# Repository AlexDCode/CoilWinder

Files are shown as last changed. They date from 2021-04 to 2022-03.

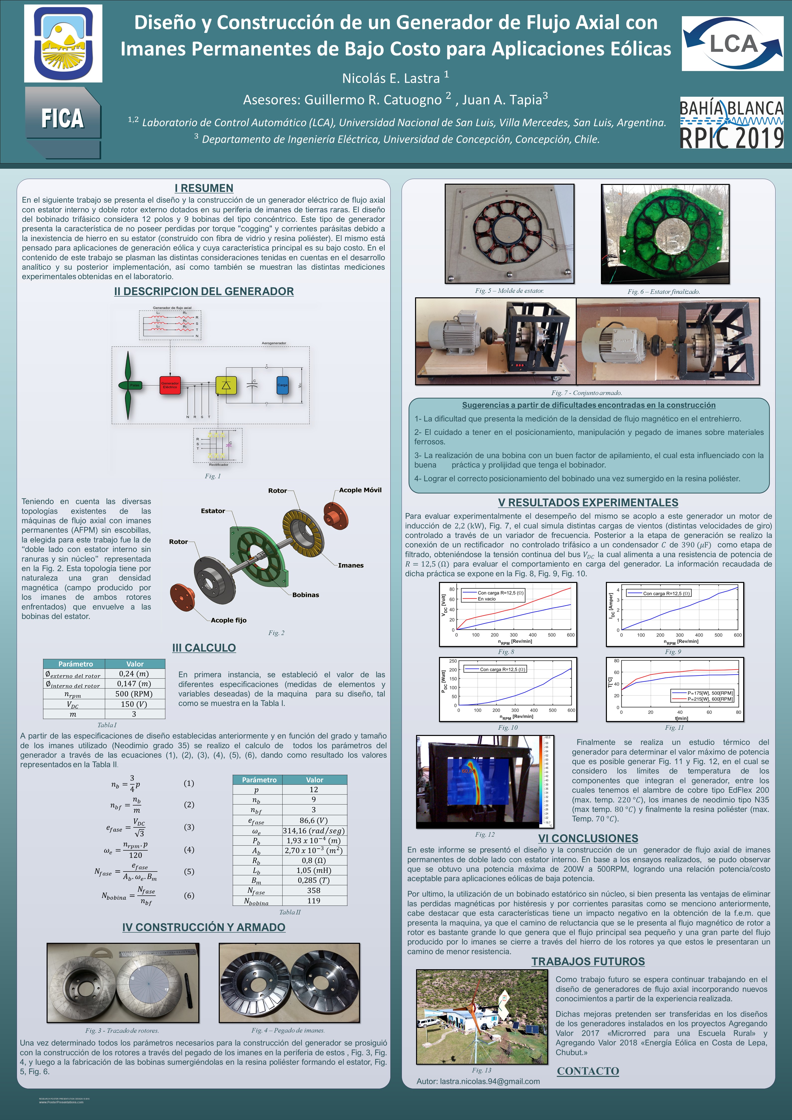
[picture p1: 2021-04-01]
docs/literature/PosterRPICestudiantilLastraNicolas-FormatoJPEG.jpg

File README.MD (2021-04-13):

# Coil Winder Final Project



## Introduction
The goal of the project is to develop an automatic coil winding machine using commands via the serial communication.

This is just a place to store and share source code, images, and important references for documentation.

Place the source code inside the src folder, the libraries for the code in the lib folder, media files in the assets folder, and other documentation at the docs folder.

## TODO:
    * MasterControl:
      * Creating the LCD display Menu
        * Configure and Run CoilWinder
        * Progress Screen
        * Settings
      * Create a send command function that takes the parameters for the instruction and sends the data in Serial/I2C Bus
      * Use I2C for sending and receiving commands and connect to SparkFun Quiic Interface Bus
    * CoilWinder:
      * Create a send command function that takes the parameters for the instruction and sends the data in Serial/I2C Bus (also in MasterControl)
      * Use I2C for sending and receiving commands and connect to SparkFun Quiic Interface Bus (also in MasterControl)
      * Add Pinout description from hardware/Schematics/Circuit Pinouts.docx in the intro commentary @ghiraldo5
      * Verify Command Instruction Set to be compressed to 1 byte instruction, that would only make the instruction command and number to be send in a single packet and represented by an hex number @ByteCommando
      * Verify parsing function to identify and execute commands (Consider separating instruction command and number as needed) @ByteCommando
      * Create overrideSpeed() function to change the speed of the winding to a percentage of the established RPM using a potentiometer @AlexDCode
      * Create overideFeederOffset() to change the feeder offset during execution @AlexDCode
    * Hardware
      * Upgrade to Trinamic TMC2208 stepper drivers

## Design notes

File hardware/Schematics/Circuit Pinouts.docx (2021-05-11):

# Microcontroller

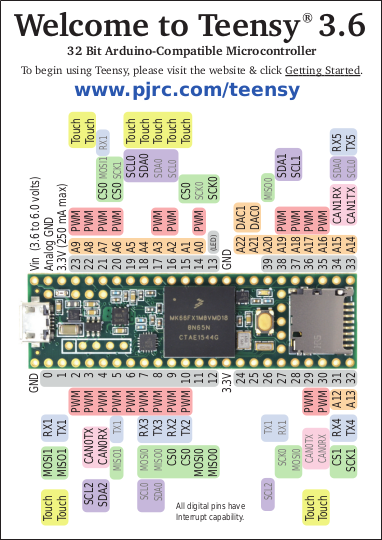
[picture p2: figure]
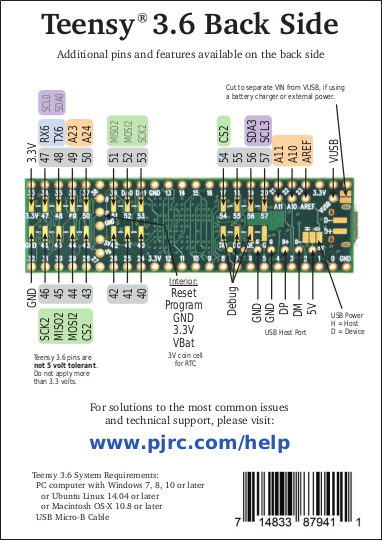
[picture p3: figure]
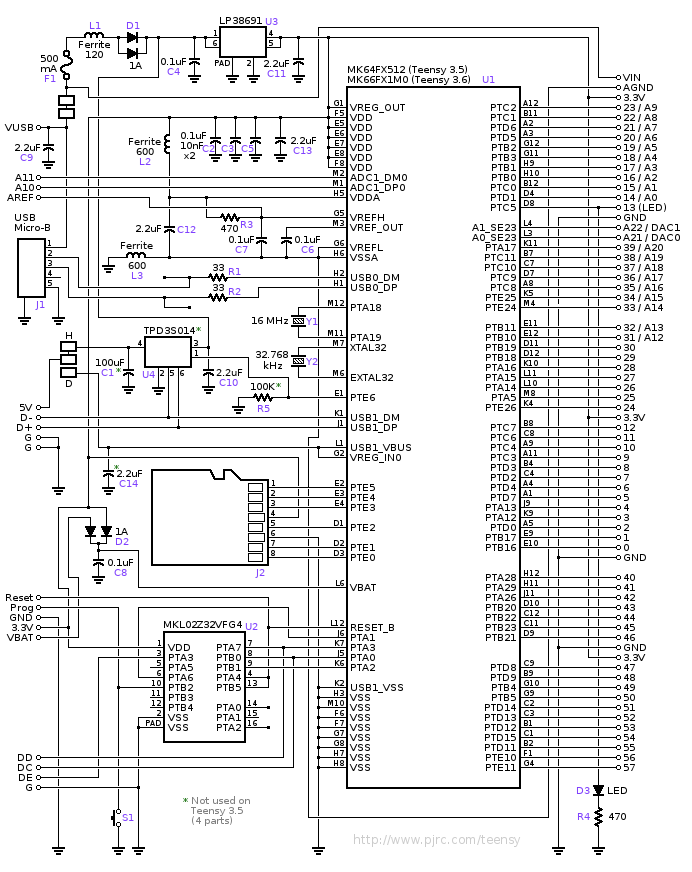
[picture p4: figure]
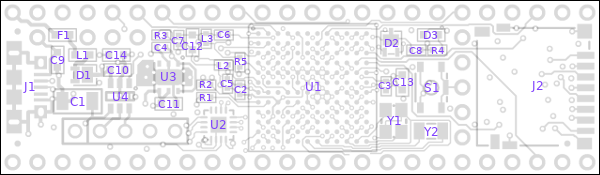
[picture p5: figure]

https://www.pjrc.com/teensy/schematic.html

# A4988 Stepper Motor Driver

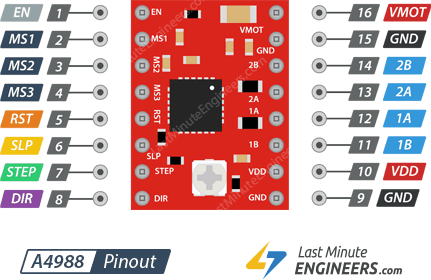
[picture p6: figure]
A4988 Stepper Motor Driver Pinout

https://lastminuteengineers.com/a4988-stepper-motor-driver-arduino-tutorial/

# Pinout Table

Teensy 3.6 | Description | Terminal Connection
0 | RX1 Communication with slave | Slave TX
1 | TX1 Communication with slave | Slave RX
7 | End stop micro switch: Feeder Secondary Tower | -
8 | End stop micro switch: Feeder Primary Tower | -
21 | Feeder Enable | Feeder A4988: EN
20 | Feeder MS1 | Feeder A4988: MS1
19 | Feeder MS2 | Feeder A4988: MS2
18 | Feeder MS3 | Feeder A4988: MS3
17 | Feeder Reset | Feeder A4988: RST
16 | Feeder Sleep | Feeder A4988: SLP
15 | Feeder Step | Feeder A4988: STEP
14 | Feeder Direction | Feeder A4988: DIR
31 | Spindle Enable | Spindle A4988: EN
32 | Spindle MS1 | Spindle A4988: MS1
39 | Spindle MS2 | Spindle A4988: MS2
38 | Spindle MS3 | Spindle A4988: MS3
35 | Spindle Reset | Spindle A4988: RST
34 | Spindle Sleep | Spindle A4988: SLP
37 | Spindle Step | Spindle A4988: STEP
36 | Spindle Direction | Spindle A4988: DIR
| SDA
| SCL

# Variables

#define Constants for Pins

Name | Description | Value
PIN_RX | RX1 Communication with slave | 0
PIN_TX | TX1 Communication with slave | 1
PIN_END_STOP_2 | End stop micro switch: Feeder Secondary Tower | 7
PIN_END_STOP_1 | End stop micro switch: Feeder Primary Tower | 8
PIN_FEEDER_EN | Feeder Enable | 21
PIN_FEEDER_MS1 | Feeder MS1 | 20
PIN_FEEDER_MS2 | Feeder MS2 | 19
PIN_FEEDER_MS3 | Feeder MS3 | 18
PIN_FEEDER_RST | Feeder Reset | 17
PIN_FEEDER_SLP | Feeder Sleep | 16
PIN_FEEDER_STEP | Feeder Step | 15
PIN_FEEDER_DIR | Feeder Direction | 14
PIN_SPINDLE_EN | Spindle Enable | 31
PIN_SPINDLE_MS1 | Spindle MS1 | 32
PIN_SPINDLE_MS2 | Spindle MS2 | 39
PIN_SPINDLE_MS3 | Spindle MS3 | 38
PIN_SPINDLE_RST | Spindle Reset | 35
PIN_SPINDLE_SLP | Spindle Sleep | 34
PIN_SPINDLE_STEP | Spindle Step | 37
PIN_SPINDLE_DIR | Spindle Direction | 36
SERIAL_BAUD_RATE | Serial Baud Rate | 115200

# Useful Links

- https://learn.sparkfun.com/tutorials/getting-started-with-the-teensy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
- https://lastminuteengineers.com/a4988-stepper-motor-driver-arduino-tutorial/
- https://www.pjrc.com/store/teensy36.html

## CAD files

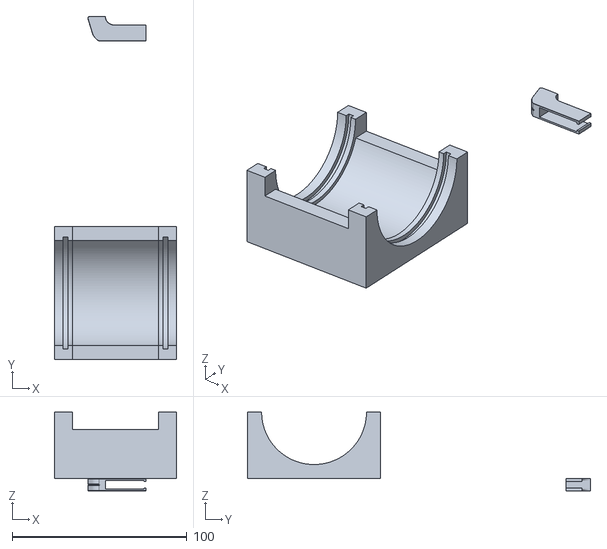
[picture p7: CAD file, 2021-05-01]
hardware/The Machine/3D Models/Coil Winder - Feeder Guide Base.stl
70.0 x 196.3 x 45.1

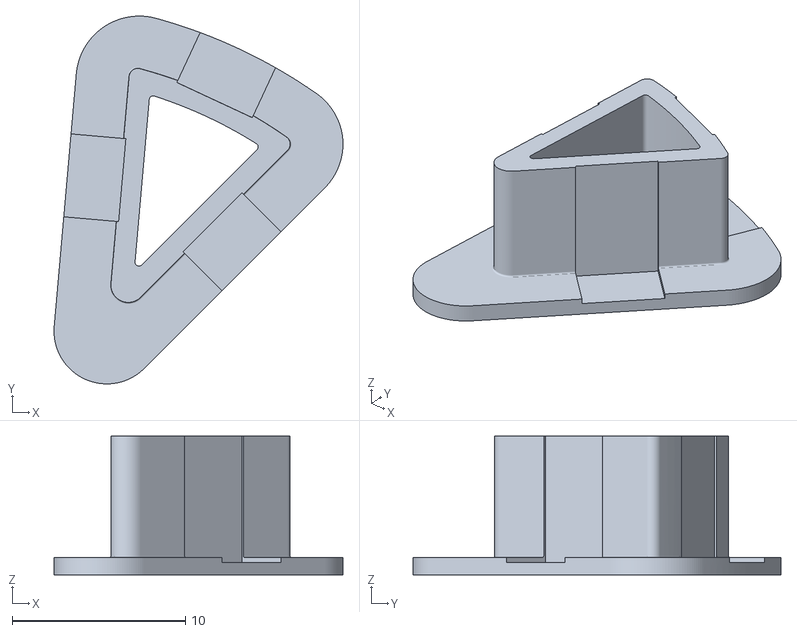
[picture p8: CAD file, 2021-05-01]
hardware/The Machine/3D Models/Coil Winder - Spindle Coil Core (Small).stl
16.7 x 21.2 x 8.00

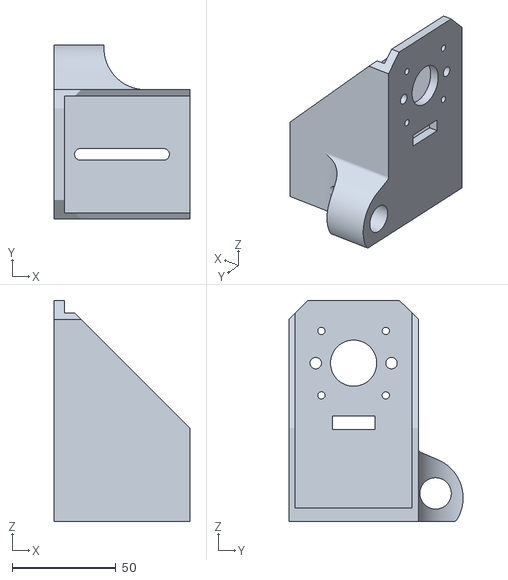
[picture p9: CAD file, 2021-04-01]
hardware/The Machine/3D Models/Coil Winder - Spindle Secondary Tower.stl
65.3 x 83.8 x 106.3

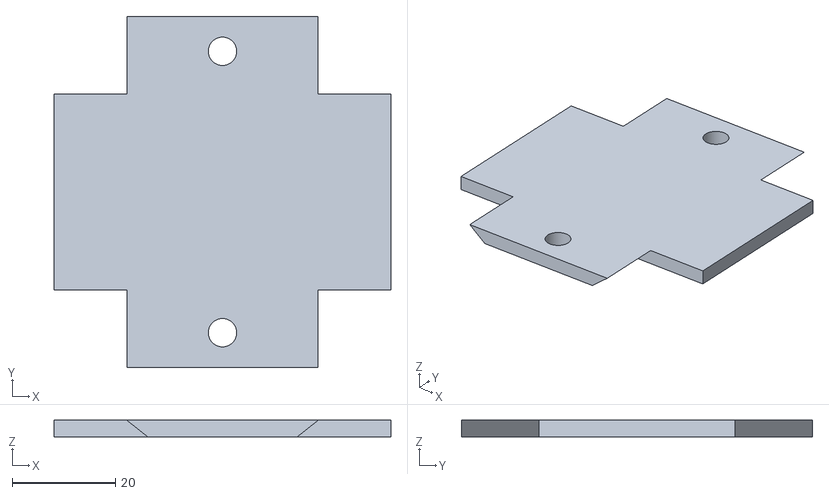
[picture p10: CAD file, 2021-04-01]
hardware/The Machine/3D Models/Coil Winder - Towers Middle Plate.stl
65.3 x 68.1 x 3.21

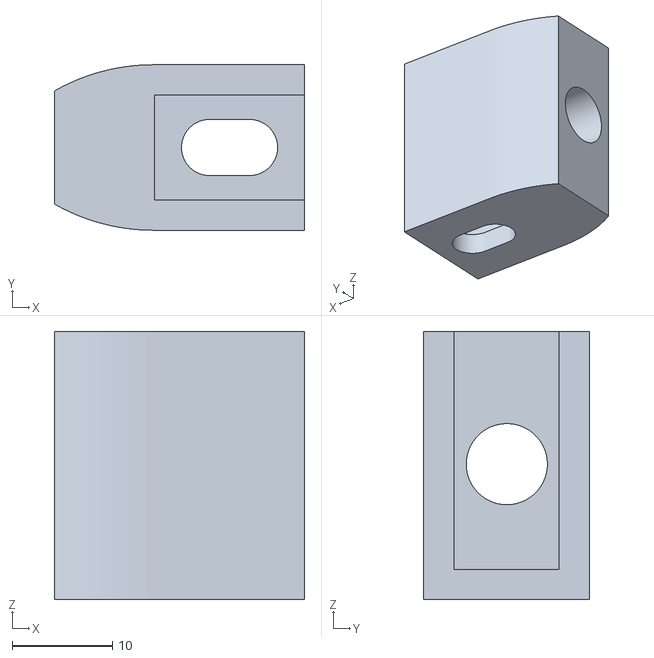
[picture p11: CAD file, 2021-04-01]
hardware/The Machine/3D Models/Coil Winder - Spindle Tower End Stop.stl
25.0 x 16.5 x 26.8

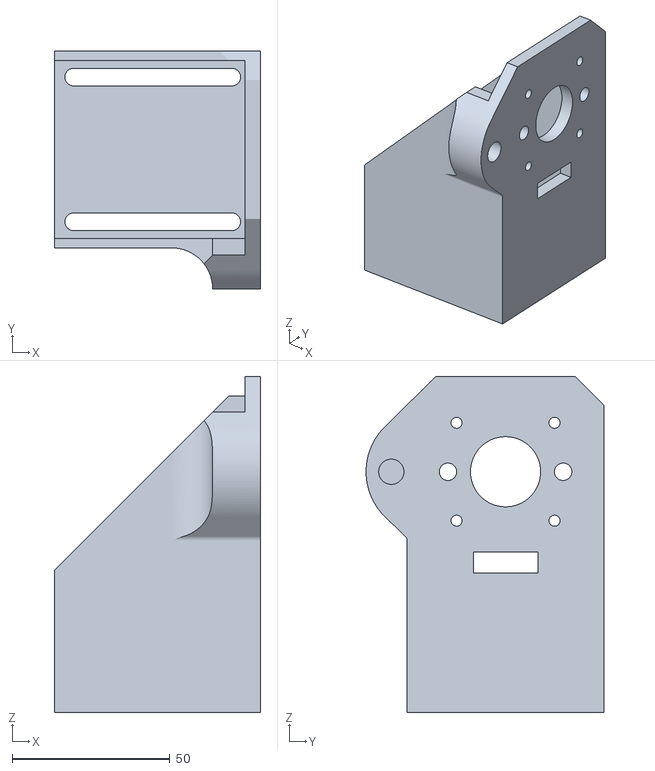
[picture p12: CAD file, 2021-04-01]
hardware/The Machine/3D Models/Coil Winder - Feeder Primary Tower.stl
65.3 x 75.3 x 106.4

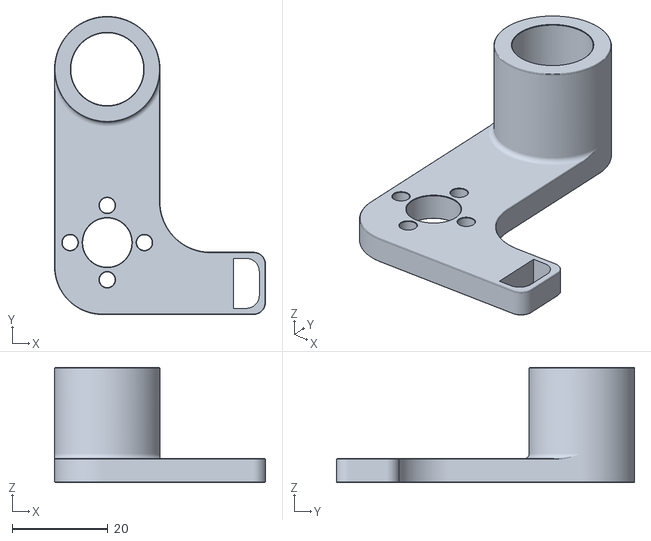
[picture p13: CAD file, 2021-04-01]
hardware/The Machine/3D Models/Coil Winder - Feeder Guide.stl
44.0 x 62.2 x 24.0

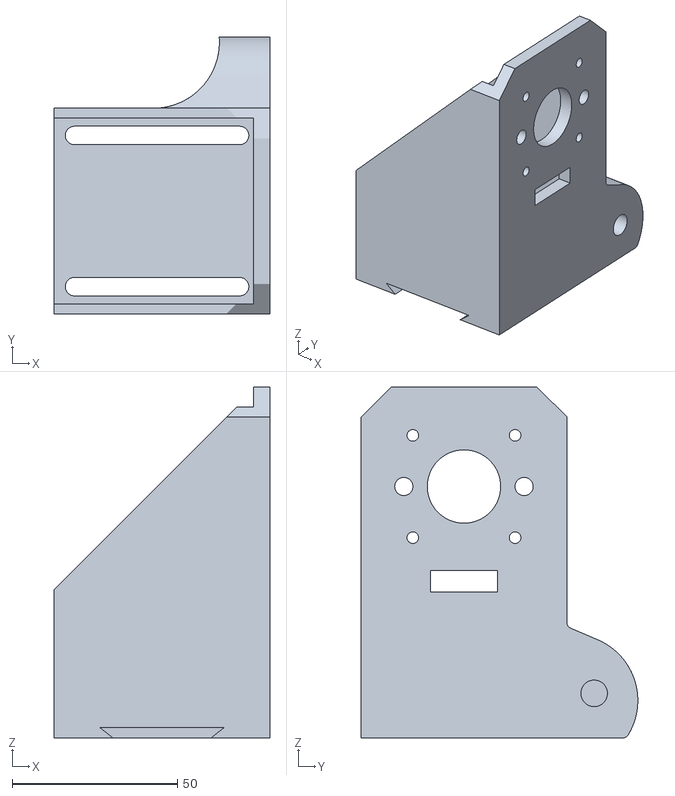
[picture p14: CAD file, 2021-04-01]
hardware/The Machine/3D Models/Coil Winder - Spindle Primary Tower.stl
65.3 x 83.8 x 106.4

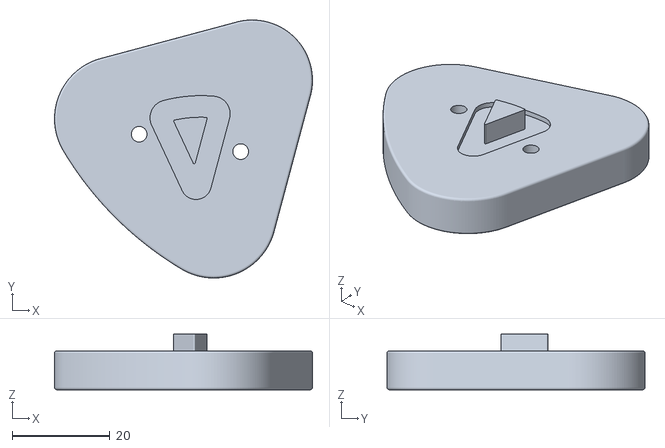
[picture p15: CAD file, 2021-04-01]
hardware/The Machine/3D Models/Coil Winder - Spindle Coil Holder Primary (Small).stl
52.8 x 52.8 x 11.4

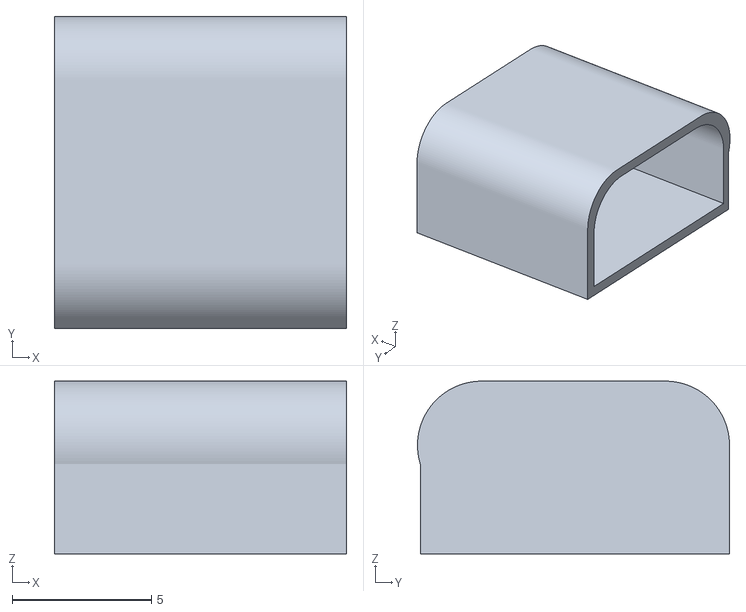
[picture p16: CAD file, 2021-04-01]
hardware/The Machine/3D Models/Coil Winder - Feeder Guide Extension Cap.stl
10.5 x 11.2 x 6.20

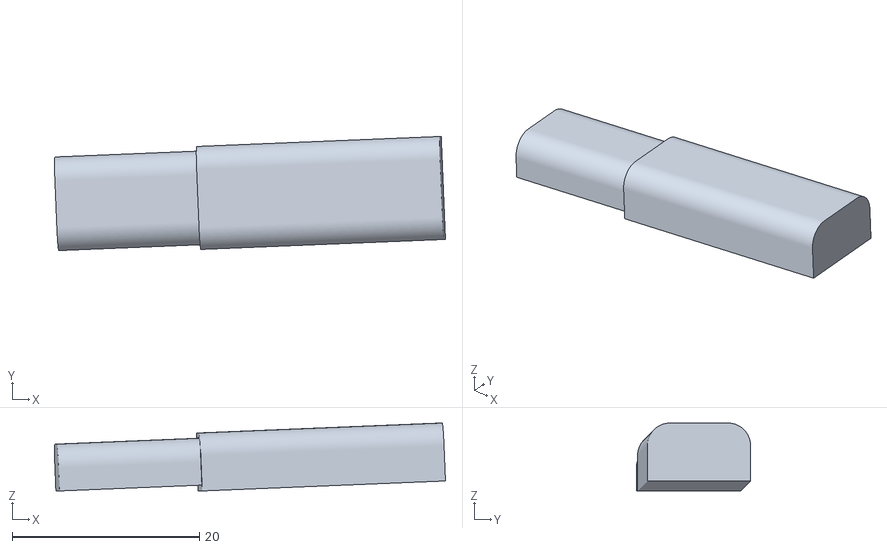
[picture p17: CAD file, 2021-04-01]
hardware/The Machine/3D Models/Coil Winder - Feeder Guide Extension.stl
41.7 x 12.2 x 7.25

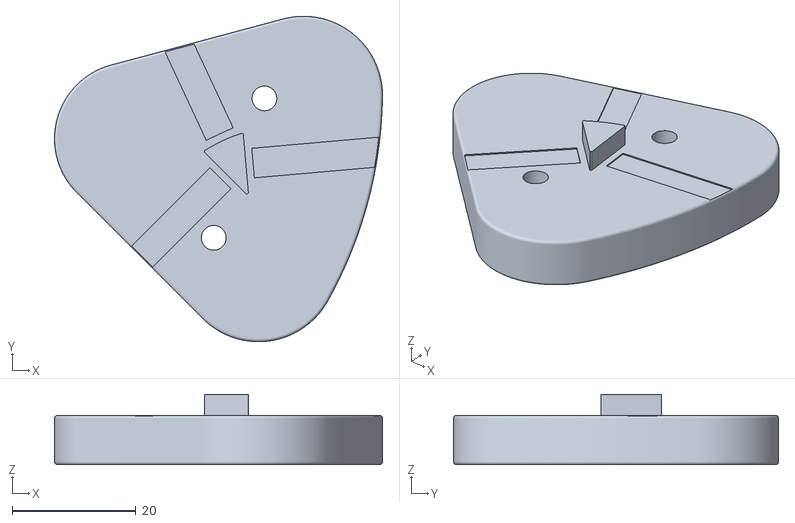
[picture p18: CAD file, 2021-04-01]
hardware/The Machine/3D Models/Coil Winder - Spindle Coil Holder Secondary (Small).stl
53.1 x 52.6 x 11.4

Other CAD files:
hardware/The Machine/3D Models/Coil Winder - Feeder Secondary Tower.stl

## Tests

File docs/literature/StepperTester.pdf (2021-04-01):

#define stepPin 2

#define dirPin 3

#define enablePin 4

void setup()
{
// We set the enable pin to be an output
pinMode(enablePin, OUTPUT);
// then we set it HIGH so that the board is disabled until we // get into a known state.
digitalWrite(enablePin, HIGH);

Serial.begin(9600);
Serial.println("Starting stepper exerciser.");

pinMode(stepPin, OUTPUT);
pinMode(dirPin, OUTPUT);
}

void loop()
{
int j;
// set the enablePin low so that we can now use our stepper driver. digitalWrite(enablePin, LOW);
// wait a few microseconds for the enable to take effect
// (That isn't in the spec sheet I just added it for sanity.) delayMicroseconds(2);
// we set the direction pin in an arbitrary direction. digitalWrite(dirPin, HIGH);

for(j=0; j<=10000; j++) {
digitalWrite(stepPin, LOW); delayMicroseconds(2);
digitalWrite(stepPin, HIGH); delayMicroseconds(1000);
}
}

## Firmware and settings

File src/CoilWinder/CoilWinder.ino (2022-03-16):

/*
!! Automatic Orthocyclic Coil Winder Implementing Linear Winding
  Modified May 10, 2021
  by: Alex D. Santiago Vargas

  This system controls the winding process according to the inputs received by the MasterControl
  The commands can be sent via any device with serial communication or I2C.


  ?Hardware Connections:
      From Circuit Pinout.docx

  ?Command Instruction Set:
      (int16_t)command (int16_t)value

    000 -> Print help message in serial
    001 -> Define Coil Width
    002 -> Define Coil Wire Gauge in mm
    003 -> Define Coil Turns
    010 -> Characterize Coil with saved parameters
    011 -> Build Coil with saved parameters
    020 -> Get saved coil_width
    021 -> Get saved wire_gauge_mm
    022 -> Get saved turns
    023 -> Get calculated number of layers
    024 -> Get calculated turns per layer
    025 -> Get calculated coil height
    030 -> Turn Steppers Off
    031 -> Turn Steppers On
    032 -> Home the feeder
    033 -> Get leading motor speed
    034 -> Get feeder position in steps
    035 -> Get spindle position in steps
    036 -> Get completed turns
    040 -> Change Feeder RPM
    041 -> Change Feeder ACCEL
    042 -> Change Feeder DECEL
    043 -> Change Feeder POLARITY
    044 -> Change Spindle RPM
    045 -> Change Spindle ACCEL
    046 -> Change Spindle DECEL
    047 -> Change Spindle POLARITY
    048 -> Change Microstepping Resolution
    050 -> Change feeder offset
    099 -> Load Default Setings

    Example:
      (int16_t)41 (int16_t)1500

  ---------------- TODO: ----------------
  * Add resume function to the winding process
  * Update pinout
*/

// Libraries
#include <Arduino.h>
#include <Wire.h>
#include "CoilWinder.h"
#include "EEPROM.h"
#include "TeensyStep.h"
#include <math.h>
#include <vector>
#include <LiquidMenu.h> // Lib for Menu (https://github.com/VasilKalchev/LiquidMenu)
#include <SerLCD.h>     // SparkFun Quiic LCD Library http://librarymanager/All#SparkFun_SerLCD

// Stepper Motor Settings variables
int16_t FEEDER_RPM;
int16_t SPINDLE_RPM;
uint16_t FEEDER_ACCEL;
uint16_t FEEDER_DECEL;
uint16_t SPINDLE_ACCEL;
uint16_t SPINDLE_DECEL;
uint16_t FEEDER_OFFSET;
boolean FEEDER_POLARITY;
boolean SPINDLE_POLARITY;
uint8_t MICROSTEPS;
uint32_t STEPS_PER_REV;
float FEEDER_STEPS_PER_MILIMETER;
int16_t instruction[COMMAND_SIZE];

// Stepper Driver Objects for feeder ans spindle
Stepper feeder(FEEDER_STEP_PIN, FEEDER_DIR_PIN);
Stepper spindle(SPINDLE_STEP_PIN, SPINDLE_DIR_PIN);

// Stepper Drivers Controller
StepControl step_controller(STEP_PULSE_WIDTH, SPEED_UPDATE_PERIOD); // Moving by position

// Flags
volatile bool homingRequired = true;
volatile bool menuPressed = false;
volatile bool clkLastState = false;
volatile bool clkState = false;
volatile bool pause_flag = false;
volatile uint32_t layerN = 0;

// Vectors to store stepper movements in steps. They are global so that they canà be accessed by all the program
std::vector<int32_t> coil_feederSteps;
std::vector<int32_t> coil_spindleSteps;

// Store calculated coil parameters
uint32_t layers;
uint32_t turns = 220;
float coil_width = 10.0;
float wire_gauge_mm = 0.51;
float turns_per_layer;
uint8_t progress_percentage;
float calculated_height;

SerLCD lcd; // Initialize the library with default I2C address 0x72

// Welcome Screen Lines
LiquidLine welcome_line1(2, 1, "Coil Winder v1.1");
LiquidLine welcome_line2(4, 2, "March 16, 2022");

// Welcome Screen
LiquidScreen welcome_screen(welcome_line1, welcome_line2);

// Set up screen lines
LiquidLine setup_line_coil_width(1, 0, "Width (mm): ", coil_width);
LiquidLine setup_line_wire_gauge(1, 1, "Gauge (mm): ", wire_gauge_mm);
LiquidLine setup_line_turns(1, 2, "Turns: ", turns);
LiquidLine setup_line_start(12, 3, "> Start");

// Set Up Screen
LiquidScreen setup_screen(setup_line_coil_width, setup_line_wire_gauge, setup_line_turns, setup_line_start);

// Progress screen lines
LiquidLine progress_line_percentage(1, 0, "Progress (%): ", progress_percentage);
LiquidLine progress_line_coil_height(1, 1, "Height (mm): ", calculated_height);
LiquidLine progress_line_pause(12, 3, "> Pause ");

LiquidScreen progress_screen(progress_line_percentage, progress_line_coil_height, progress_line_pause);

LiquidMenu menu(lcd);

void setup()
{
  // Start serial communication
  delay(1000);
  tone(BUZZER_PIN, 100, 3000);

  // Start Serial and I2C Communication
  Serial.begin(SERIAL_BAUD_RATE);
  Wire2.begin(LCD_ADDRESS);
  Wire2.setClock(400000); // Optional - set I2C SCL to High Speed Mode of 400kHz
  lcd.begin(Wire2);
  lcd.setBacklight(255, 0, 0); // bright red

  setup_line_coil_width.set_decimalPlaces(1);
  setup_line_wire_gauge.set_decimalPlaces(3);
  progress_line_percentage.set_decimalPlaces(0);
  progress_line_coil_height.set_decimalPlaces(1);

  // identificar a que lado aparece la flecha setup screen
  setup_line_start.set_focusPosition(Position::LEFT);
  progress_line_pause.set_focusPosition(Position::LEFT);

  // Identify tge display line count
  setup_screen.set_displayLineCount(4);
  progress_screen.set_displayLineCount(4);

  // Load settings from the EEPROM memory to save when power is lost
  EEPROM.get(FEEDER_RPM_ADDRESS, FEEDER_RPM);
  EEPROM.get(SPINDLE_RPM_ADDRESS, SPINDLE_RPM);
  EEPROM.get(FEEDER_ACCEL_ADDRESS, FEEDER_ACCEL);
  EEPROM.get(FEEDER_DECEL_ADDRESS, FEEDER_DECEL);
  EEPROM.get(FEEDER_OFFSET_ADDRESS, FEEDER_OFFSET);
  EEPROM.get(SPINDLE_ACCEL_ADDRESS, SPINDLE_ACCEL);
  EEPROM.get(SPINDLE_DECEL_ADDRESS, SPINDLE_DECEL);
  EEPROM.get(FEEDER_POLARITY_ADDRESS, FEEDER_POLARITY);
  EEPROM.get(SPINDLE_POLARITY_ADDRESS, SPINDLE_POLARITY);
  EEPROM.get(MICROSTEPS_ADDRESS, MICROSTEPS);

  STEPS_PER_REV = MOTOR_STEPS * MICROSTEPS;
  FEEDER_STEPS_PER_MILIMETER = STEPS_PER_REV / LEADSCREW_PITCH; // 1 revolution moves 2 mm

  // Micro switch as inputs with pullup resistors
  pinMode(END_STOP_2_PIN, INPUT_PULLUP);
  pinMode(END_STOP_1_PIN, INPUT_PULLUP);
  pinMode(SW_PIN, INPUT_PULLUP);

  // Stepper pins as outputs
  pinMode(FEEDER_RST_PIN, OUTPUT);
  pinMode(SPINDLE_RST_PIN, OUTPUT);
  pinMode(FEEDER_EN_PIN, OUTPUT);
  pinMode(SPINDLE_EN_PIN, OUTPUT);
  pinMode(SPINDLE_SLP_PIN, OUTPUT);
  pinMode(FEEDER_SLP_PIN, OUTPUT);

  // Other pins
  pinMode(LED_BUILTIN, OUTPUT);
  pinMode(STATUS_LED_PIN_R, OUTPUT);

  // Load settings into stepper motor objects
  feeder
      .setMaxSpeed(FEEDER_RPM)              // steps/s
      .setAcceleration(FEEDER_ACCEL)        // steps/s^2
      .setInverseRotation(FEEDER_POLARITY)  // Software will run stepper forward
      .setStepPinPolarity(FEEDER_POLARITY); // driver expects active high pulses

  spindle
      .setMaxSpeed(SPINDLE_RPM)              // steps/s
      .setAcceleration(SPINDLE_ACCEL)        // steps/s^2
      .setInverseRotation(SPINDLE_POLARITY)  // Software will run stepper forward
      .setStepPinPolarity(SPINDLE_POLARITY); // driver expects active high pulses

  // Set the microstepping pins states
  setMicrostepping(MICROSTEPS, FEEDER_MS1_PIN, FEEDER_MS2_PIN, FEEDER_MS3_PIN);
  setMicrostepping(MICROSTEPS, SPINDLE_MS1_PIN, SPINDLE_MS2_PIN, SPINDLE_MS3_PIN);

  // loadDefaultSettings(); // Load Default Settings at startup; Comment to avoid

  // Attach falling hardware interrupts for end stops that are normally high, active low
  attachInterrupt(digitalPinToInterrupt(END_STOP_1_PIN), emergencyStop, FALLING);
  attachInterrupt(digitalPinToInterrupt(END_STOP_2_PIN), emergencyStop, FALLING);
  attachInterrupt(digitalPinToInterrupt(STOP_BTN), emergencyStop, FALLING);
  attachInterrupt(digitalPinToInterrupt(SW_PIN), menuPress, LOW);

  // This is the method used to add a screen object to the menu.
  menu.add_screen(welcome_screen);
  menu.add_screen(setup_screen);
  menu.add_screen(progress_screen);

  menu.change_screen(1);
  feederHomming();

  menu.change_screen(2);
  menu.set_focusedLine(3);
  menu.update();

  printHelp();
}

void loop()
{
  // Home the feeder if the flag is set
  if (homingRequired)
    feederHomming();

  // Execute function when pressing
  if (menuPressed)
  {
    menuPressed = false;
    buildCoil();
  }

  // If data is incomming decode the instruction and execute accordingly
  if (Serial.available())
    decodeSerial();

  delay(25);
}

void loadDefaultSettings()
{
  // Write the default setting values into the EEPROM
  EEPROM.put(FEEDER_RPM_ADDRESS, (uint16_t)FEEDER_RPM_DEFAULT);
  EEPROM.put(SPINDLE_RPM_ADDRESS, (uint16_t)SPINDLE_RPM_DEFAULT);
  EEPROM.put(FEEDER_ACCEL_ADDRESS, (uint16_t)FEEDER_ACCEL_DEFAULT);
  EEPROM.put(FEEDER_DECEL_ADDRESS, (uint16_t)FEEDER_DECEL_DEFAULT);
  EEPROM.put(FEEDER_OFFSET_ADDRESS, (uint16_t)FEEDER_OFFSET_DEFAULT);
  EEPROM.put(SPINDLE_ACCEL_ADDRESS, (uint16_t)SPINDLE_ACCEL_DEFAULT);
  EEPROM.put(SPINDLE_DECEL_ADDRESS, (uint16_t)SPINDLE_DECEL_DEFAULT);
  EEPROM.put(FEEDER_POLARITY_ADDRESS, (bool)FEEDER_POLARITY_DEFAULT);
  EEPROM.put(SPINDLE_POLARITY_ADDRESS, (bool)SPINDLE_POLARITY_DEFAULT);
  EEPROM.put(MICROSTEPS_ADDRESS, (uint8_t)MICROSTEPS_DEFAULT);
}

void setMicrostepping(uint16_t _Microstep, uint16_t _ms1_pin, uint16_t _ms2_pin, uint16_t _ms3_pin)
{

  /*
  The A4988 driver has the following options for microstepping:

*   ------------ Microstepping Table ------------
!!  MS1:    MS2:    MS3:    Microstep Resolution:
    Low	    Low	    Low	    Full step
    High    Low	    Low	    Half step
    Low     High    Low	    Quarter step
    High    High    Low	    Eighth step
    High    High    High    Sixteenth step
  */

  // Mask for the different microstepping pin states in MS3 MS2 MS1 order
  uint8_t MicrosteppingTable[] = {0b000, 0b001, 0b010, 0b011, 0b111};

  // Set all microstepping pins as outputs
  pinMode(_ms1_pin, OUTPUT);
  pinMode(_ms2_pin, OUTPUT);
  pinMode(_ms3_pin, OUTPUT);

  /* Select mask according to the microstep input

    If we calculate X by taking the log2 of Microstep = 2^X, we would have an index
    from 0 to 4 representing the all microstepping resolutions of the A4988. Hence we
    input full (1), half (2), quarter (4), eighth (8), or sixteenth (16) resolution and
    we get the corresponding mask from element X of the table array.

    Example:
      For 16-Steps resolution we have:

      log2(16) = 4 => _microsteppingMask = MicrosteppingTable[4]
      => _microsteppingMask = 0b111

      Q.E.D. (quod erat demonstrandum) <=> TRIVIAL
  */
  uint8_t _microsteppingMask = MicrosteppingTable[uint8_t(log2(_Microstep))];

  /* Write the corresponfing mask bit to the microstepping pins

    We can select the corresponding output state by making a bitwise-AND with only the
    bit of the pin we want to write (MS1,MS2,MS3) as 1 and all others as 0. Then we shift
    to the right to move the state to be written to the first bit

    Example:
      For 16-Steps resolution, we have _microsteppingMask = 0b111

      => digitalWrite(_ms1_pin, (0b111 & 0b001) >> 0)
      => digitalWrite(_ms2_pin, (0b111 & 0b010) >> 1)
      => digitalWrite(_ms3_pin, (0b111 & 0b100) >> 2)

      => digitalWrite(_ms1_pin, 0b001 >> 0)
      => digitalWrite(_ms2_pin, 0b010 >> 1)
      => digitalWrite(_ms3_pin, 0b100 >> 2)

      => digitalWrite(_ms1_pin, 1)
      => digitalWrite(_ms2_pin, 1)
      => digitalWrite(_ms3_pin, 1)

      Q.E.D. (quod erat demonstrandum) <=> TRIVIAL
  */
  digitalWrite(_ms1_pin, (_microsteppingMask & 0b001) >> 0);
  digitalWrite(_ms2_pin, (_microsteppingMask & 0b010) >> 1);
  digitalWrite(_ms3_pin, (_microsteppingMask & 0b100) >> 2);
}

void pause_resume()
{
  /*
    When the user wants to pause the build, this reduces the speeds and avoids loosing steps in order to keep winding from the pause point
  */
  pause_flag = !pause_flag;
}

void emergencyStop()
{
  /*
    When an end stop falls, activates this Interrupt Service Routine
    to innmediatly stop the winder no matter what, possibly missing steps
    from sudden braking. Hence it raises the homingRequired flag to home
    before running again
  */
  step_controller.emergencyStop();
  homingRequired = true;
}

void turnOnSteppers()
{
  /*
    !! Enable Pin:
    is active low input, when pulled LOW the A4988 driver is
    enabled. By default this pin is pulled low, unless you pull it HIGH.

    !! Sleep Pin:
    is active low input. Meaning, pulling this pin LOW puts the
    driver in sleep mode, minimizing the power consumption. You can invoke
    this especially when the motor is not in use

    !! Reset Pin
    is an active low input, when pulled LOW all STEP inputs are
    ignored, until you pull it HIGH. It also resets the driver by setting
    the internal translator to a predefined Home state. Home state is the
    initial position from where the motor starts and depends on the
    microstep resolution.
  */
  tone(BUZZER_PIN, 5000, 500); // Buzzer Activation before starting wilding process
  digitalWrite(STATUS_LED_PIN_R, HIGH);

  digitalWrite(FEEDER_EN_PIN, LOW);   // Feeder Stepper Driver Enable
  digitalWrite(FEEDER_SLP_PIN, HIGH); // Feeder Stepper Driver Wake-Up (Un-Sleep)
  digitalWrite(FEEDER_RST_PIN, HIGH); // Feeder Stepper Driver Reset

  digitalWrite(SPINDLE_EN_PIN, LOW);   // Spindle Stepper Driver Enable
  digitalWrite(SPINDLE_SLP_PIN, HIGH); // Spindle Stepper Driver Wake-Up (Un-Sleep)
  digitalWrite(SPINDLE_RST_PIN, HIGH); // Spindle Stepper Driver Reset

  digitalWrite(LED_BUILTIN, HIGH); // BuiltIn LED On to indicate enabled steppers
}

void turnOffSteppers()
{
  /*
    !! Enable Pin:
    is active low input, when pulled LOW the A4988 driver is
    enabled. By default this pin is pulled low, unless you pull it HIGH.

    !! Sleep Pin:
    is active low input. Meaning, pulling this pin LOW puts the
    driver in sleep mode, minimizing the power consumption. You can invoke
    this especially when the motor is not in use

    !! Reset Pin
    is an active low input, when pulled LOW all STEP inputs are
    ignored, until you pull it HIGH. It also resets the driver by setting
    the internal translator to a predefined Home state. Home state is the
    initial position from where the motor starts and depends on the
    microstep resolution.
  */

  digitalWrite(FEEDER_EN_PIN, HIGH); // Feeder Stepper Driver Disable
  digitalWrite(FEEDER_SLP_PIN, LOW); // Feeder Stepper Driver Sleep

  digitalWrite(SPINDLE_EN_PIN, HIGH); // Spindle Stepper Driver Disable
  digitalWrite(SPINDLE_SLP_PIN, LOW); // Spindle Stepper Driver Sleep

  digitalWrite(LED_BUILTIN, LOW); // BuiltIn LED Off to indicate disable steppers

  noTone(BUZZER_PIN);
  digitalWrite(STATUS_LED_PIN_R, LOW);
}

void feederHomming()
{
  // Ensure all steppers are On and disable/put to sleep the spindle
  turnOnSteppers();
  digitalWrite(SPINDLE_EN_PIN, HIGH); // Spindle Stepper Driver Disable
  digitalWrite(SPINDLE_SLP_PIN, LOW); // Spindle Stepper Driver Sleep

  // Decrease the maximum speed and acceleration of the feeder by a factor
  feeder.setMaxSpeed(FEEDER_RPM / 2);
  feeder.setAcceleration(FEEDER_ACCEL / 2);

  // Read the state of the right end stop, its negated for programming logic because its active low
  boolean rightLimit = !digitalRead(END_STOP_1_PIN);

  // Move to the right until the right end stop is activated
  feeder.setTargetRel(-500000);
  step_controller.moveAsync(feeder);
  while (!rightLimit)
    rightLimit = !digitalRead(END_STOP_1_PIN);

  step_controller.stop();

  // WHen is at the far most right, move step by step to the left until the end stop is deactivated
  while (rightLimit)
  {
    feeder.setTargetRel(1);
    step_controller.move(feeder);
    rightLimit = !digitalRead(END_STOP_1_PIN);
  }

  // Move extra steps as home position buffer
  feeder.setTargetRel(FEEDER_OFFSET);
  step_controller.move(feeder);

  // Turn off all the steppers to avoid movement during home position reset
  turnOffSteppers();

  // Pull down and then up to reset the feeder driver internal home state
  digitalWrite(FEEDER_RST_PIN, LOW); // Feeder Stepper Driver Reset
  delay(100);
  digitalWrite(FEEDER_RST_PIN, HIGH); // Feeder Stepper Driver Reset
  // Get the current position in software and set is as the new one
  feeder.setPosition(feeder.getPosition());

  // Set the feeder speed and acceleration to normal
  feeder.setMaxSpeed(FEEDER_RPM);
  feeder.setAcceleration(FEEDER_ACCEL);

  // Lower the homingRequired flag as it has homed
  homingRequired = false;
}

void coilCharacterization(float _coil_width = coil_width, float _wire_gauge_mm = wire_gauge_mm, float _turns = turns, float &_turns_per_layer = turns_per_layer, uint32_t &_layers = layers)
{
  // Set the global variables to the input values
  wire_gauge_mm = _wire_gauge_mm;
  coil_width = _coil_width;
  turns = _turns;

  // Calculate how many turns can be made for a wire of teh specified gauge and coil width
  _turns_per_layer = _coil_width / _wire_gauge_mm;

  // Calculate the total number of layers and if its a fraction of a total turn round up
  _layers = int32_t(_turns / _turns_per_layer);
  if (_turns_per_layer / _turns > _layers)
    _layers++;

  // Calculate the height of the coil layer by layer
  calculated_height = _layers * _wire_gauge_mm;
  // Print error if calculated height is bigger than established

  // Clear the motor step vectors
  coil_feederSteps.clear();
  coil_spindleSteps.clear();

  // Iterate the layers and assign the proper steps to the vectos
  for (uint32_t i = 0; i < _layers; i++)
  {
    // We move the feeder evenly from left to right for all the coil width in one direction per layer
    if (i % 2 == 0)
      // If the iteration is even means it is moving to the left, hence positive steps
      coil_feederSteps.push_back(int32_t(_coil_width * FEEDER_STEPS_PER_MILIMETER));
    else
      // If not even we are moving to the right, hence negative steps
      coil_feederSteps.push_back(int32_t(-1 * _coil_width * FEEDER_STEPS_PER_MILIMETER));

    // We rotate the spindle to wind all the estalished turns per layer
    if (i == (_layers - int32_t(1)))
      // If it is the last layer we only wind the remaining turns
      coil_spindleSteps.push_back(int32_t((_turns - (_layers - 1) * _turns_per_layer) * STEPS_PER_REV));
    else
      // For other layers we wind all the turns that can be fitted evenly into a layer
      coil_spindleSteps.push_back(int32_t(_turns_per_layer * STEPS_PER_REV));
  }
}

void buildCoil()
{
  menu.change_screen(3);
  menu.set_focusedLine(3);
  menu.update();
  coilCharacterization();

  // Starting delay
  delay(1000);

  // Home the feeder if needed
  if (homingRequired)
    feederHomming();

  turnOnSteppers();

  // Iterate for all the layers and execute the steps established in the motor step vectors
  for (layerN = 0; layerN < layers; layerN++)
  {
    // Set the steps from iteration element to the feeder and spindle
    feeder.setTargetRel(int32_t(coil_feederSteps[layerN]));
    spindle.setTargetRel(int32_t(coil_spindleSteps[layerN]));

    progress_percentage = (layerN * 100.0 / layers);
    calculated_height = (float)((layerN + 1) * wire_gauge_mm);
    menu.update();
    // If no homing is required or the motors are executing a movement start the layer winding
    if (!homingRequired && !step_controller.isRunning())
    {
      if (pause_flag)
      {
        step_controller.stopAsync();

        while (pause_flag)
        {
          if (menuPressed)
          {
            menuPressed = false;
            pause_resume();
          }

          lcd.setCursor(12, 3);
          if (pause_flag)
            lcd.print("> Resume");
          else
            lcd.print("> Pause ");

          delay(100);
        }
      }

      // Move the motors in sync but without blocking other code execution
      step_controller.moveAsync(feeder, spindle);

      // While there is no homming needed and the controller is executing a move, send the progress via serial
      while (step_controller.isRunning())
      {
        if (menuPressed)
        {
          menuPressed = false;
          pause_resume();
        }

        lcd.setCursor(12, 3);
        if (pause_flag)
          lcd.print("> Resume");
        else
          lcd.print("> Pause ");
      }
    }
    else
      break;

    delay(250);
  }

  turnOffSteppers();
  menu.previous_screen();
  menu.set_focusedLine(1);
  menu.update();
}

void decodeSerial()
{
  instruction[0] = (int16_t)Serial.readStringUntil(',').toInt();
  instruction[1] = (int16_t)Serial.readStringUntil(';').toInt();

  Serial.print("\nReceived Command: ");
  Serial.print(instruction[0]);
  Serial.print(" with Value: ");
  Serial.println(instruction[1]);

  decodeCommand(instruction[0], instruction[1]);
}
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

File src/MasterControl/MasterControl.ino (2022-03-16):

/*
    LiquidMenu adaption to Quiic LCD Display

    This is the get started example demonstrating how to create
    a menu of two screens with dynamically changing information.

    The first screen shows some static text. The second screen
    shows the reading of analog pin A1. To display a changing
    variable on the LCD, simply put the variable in the LiquidLine
    constructor. In this case the LiquidLine object is "analogReading_line"
    and the variable is "analogReading". This line is on the second
    screen. The value of the analog pin is read every second and if
    it has changed the display is updated with the new value. The
    menu cycles through its two screens every five seconds.

    This is adapted from the LiquidMenu library  - hello_menu.ino example to
    work with SparkFun Quiic LCD displays.

    The circuit:
    - Connect the Quiic LCD Screen to the bus

    Created July 24, 2016
        by Vasil Kalchev
    https://github.com/VasilKalchev/LiquidMenu

    Modified Apr 12, 2021
        by Alex Santiago

-------------------------------------- CONFIGURATION NOTE: --------------------------------------
    The LiquidMenu_config.h file needs to be modified in order to work with
    the QuiicSerLCD library. The following lines shall be commented:
    *   #define LIQUIDMENU_LIBRARY LiquidCrystal_LIBRARY
    *   #include <LiquidCrystal.h>
    *   #define DisplayClass LiquidCrystal

    The following lines shall be uncommented and changed from -> to:
    *   #include <LIBRARY_HEADER.h>              -> #include <SerLCD.h>
    *   #define DisplayClass LIBRARY_CONSTRUCTOR -> #define DisplayClass SerLCD

-------------------------------------------------------------------------------------------------
*/

#include <LiquidMenu.h> // Lib for Menu (https://github.com/VasilKalchev/LiquidMenu)
#include <Wire.h>       // For I2C Communication
#include <SerLCD.h>     // SparkFun Quiic LCD Library http://librarymanager/All#SparkFun_SerLCD
#include "MasterControl.h"

SerLCD lcd; // Initialize the library with default I2C address 0x72

// determine sentido que se gira el encoder
boolean clkState;
boolean clkLastState;

int16_t response[COMMAND_SIZE];
uint16_t speed = 0;
uint16_t turns = 200;
float coil_width = 8.0;
float wire_gauge_mm = 0.5;
float calculated_height = 0.0;
uint16_t progress_percentage = 0;
/*
    LiquidLine objects represent a single line of text and/or variables
    on the display. The first two parameters are the column and row from
    which the line starts, the rest of the parameters are the text and/or
    variables that will be printed on the display. They can be up to four.
*/
// Here the line is set to column 1, row 0 and will print the passed
// string and the passed variable.
LiquidLine welcome_line1(2, 0, "Coil Winder v1.0");
// Here the column is 3, the row is 2 and the string is "Hello Menu".
LiquidLine welcome_line2(4, 2, "May 12, 2021");

/*
    LiquidScreen objects represent a single screen. A screen is made of
    one or more LiquidLine objects. Up to four LiquidLine objects can
    be inserted from here, but more can be added later in setup() using
    welcome_screen.add_line(someLine_object);
*/
// Here the LiquidLine objects are the two objects from above.
LiquidScreen welcome_screen(welcome_line1, welcome_line2);

// Set up screen
LiquidLine setup_line_setuptitle(7, 0, "Set-Up");
LiquidLine setup_line_back(1, 1, "Back");
LiquidLine setup_line_coil_width(1, 1, "Width (mm): ", coil_width);
LiquidLine setup_line_wire_gauge(1, 2, "Gauge (mm): ", wire_gauge_mm);
LiquidLine setup_line_turns(1, 3, "Turns: ", turns);
LiquidLine setup_line_start(1, 0, "Start");

LiquidScreen setup_screen(setup_line_setuptitle, setup_line_coil_width, setup_line_wire_gauge, setup_line_turns);

// Progress screen
LiquidLine progress_line_percentage(1, 0, "Progress %: ", progress_percentage);
LiquidLine progress_line_coil_height(1, 1, "Height (mm): ", calculated_height);
LiquidLine progress_line_stop(1, 3, "Back");

LiquidScreen progress_screen(progress_line_percentage, progress_line_coil_height, progress_line_stop);

LiquidMenu menu(lcd);

void setup()
{
    Serial.begin(SERIAL_BAUD_RATE);
    // setup_screen.add_line(setup_line_turns);
    setup_screen.add_line(setup_line_start);

    setup_line_coil_width.set_decimalPlaces(1);
    setup_line_wire_gauge.set_decimalPlaces(3);
    progress_line_percentage.set_decimalPlaces(0);
    progress_line_coil_height.set_decimalPlaces(1);
    pinMode(BTN_A_PIN, INPUT_PULLUP);
    pinMode(BTN_B_PIN, INPUT_PULLUP);
    pinMode(BTN_C_PIN, INPUT_PULLUP);
    pinMode(CLK_PIN, INPUT_PULLUP);
    pinMode(DT_PIN, INPUT_PULLUP);
    pinMode(SW_PIN, INPUT_PULLUP);

    // identificar a que lado aparece la flecha setup screen
    setup_line_back.set_focusPosition(Position::LEFT);
    setup_line_coil_width.set_focusPosition(Position::LEFT);
    setup_line_wire_gauge.set_focusPosition(Position::LEFT);
    setup_line_turns.set_focusPosition(Position::LEFT);
    setup_line_start.set_focusPosition(Position::LEFT);

    // attach funcion a cada linea para cuando se seleccione en el menu .attach_function(identifica funcion, nobre de la funcion)
    setup_line_back.attach_function(1, back);
    setup_line_coil_width.attach_function(1, set_coil_width);
    setup_line_wire_gauge.attach_function(1, set_wire_gauge);
    setup_line_turns.attach_function(1, set_turns);
    setup_line_start.attach_function(1, start);

    // menu.add_screen(setup_screen);

    // identificar a que lado aparece la flecha progress screen
    progress_line_stop.set_focusPosition(Position::LEFT);
    // attach funcion a cada linea para cuando se seleccione en el menu .attach_function(identifica funcion, nobre de la funcion)
    progress_line_stop.attach_function(1, stop);

    // menu.add_screen(progress_screen);

    // identificar cantidad de lines en la pantalla
    setup_screen.set_displayLineCount(4);
    progress_screen.set_displayLineCount(4);

    // Serial.begin(BAUD_RATE);

    // Initalize I2C communication
    Wire.begin();
    Wire.onReceive(receiveCommand);

    lcd.begin(Wire); // Set up the LCD for I2C communication

    // This is the method used to add a screen object to the menu.
    menu.add_screen(welcome_screen);
    menu.add_screen(setup_screen);
    menu.add_screen(progress_screen);

    menu.nextScreen();
    delay(3000);

    menu.change_screen(2);
    menu.set_focusedLine(0);

    clkLastState = digitalRead(CLK_PIN);
}
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

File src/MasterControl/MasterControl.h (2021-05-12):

void receiveCommand(int numBytes);
void sendCommand(int16_t _command, int16_t _value = 0);
void requestData(byte _address, int16_t _command, int16_t _response[]);
void decodeSerial();

// Define Communication parameters
#define SERIAL_BAUD_RATE 115200
#define COIL_WINDER_I2C_ADDRESS 0x70
#define COMMAND_SIZE 2  // 2 elements of 16 bits each
#define RESPONSE_SIZE 4 // 2 bytes of command and 2 bytes of value

#define BTN_A_PIN 2
#define BTN_B_PIN 3
#define BTN_C_PIN 4
#define CLK_PIN 8
#define DT_PIN 9
#define SW_PIN 10

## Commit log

2021-04-07 Added Teensy hardware packege
2021-04-07 Added BlackBoard C drivers, corrected bit shift
    [CoilWinder.ino]
2021-05-01 Added feeder guide models
    [Coil Winder - Feeder Guide Base.stl, Coil Winder - Spindle Coil Core (Small).stl]
2021-05-01 Improved communication methods I2C and Serial
2021-05-10 Further improves on I2C and Serial communication
2022-03-16 v1.1 Working Prototype Release
